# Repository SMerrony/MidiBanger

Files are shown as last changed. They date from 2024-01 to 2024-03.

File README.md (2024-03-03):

# MidiBanger
A Raspberry Pico* MIDI device that plays physical (toy) instruments via servos.

MidiBanger supports both percussive (mallet-type) and pressed (key-type) instruments.

* Pan-and-tilt mode using just two servos to play reachable notes
* Servo-per-note mode
* Solenoid-per-note mode (soon)

The current version supports up to 16 directly-connected servos, later versions may
support I2C servo controllers allowing hundreds of servos to be used. 

*Tested on Raspberry Pi Pico, Raspberry Pi Pico W, and Waveshare RP2040-Zero.

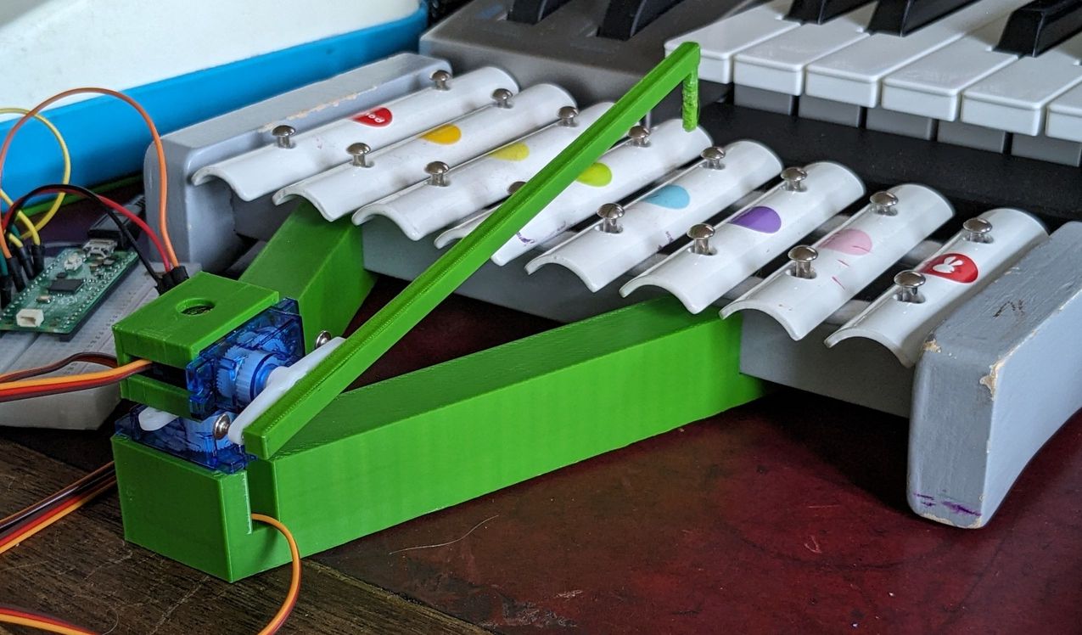
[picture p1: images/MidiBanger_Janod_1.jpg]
Pan-and-tilt version playing Janod toy glockenspiel


## Hardware Requirements
* Raspberry Pico or compatible such as RP2040-Zero
* Servo per note eg. SG90 9g Micro Servo, or a pair if using pan-and-tilt 
* Optional - Micro speaker - handy for debugging and setup
* Optional - 5V PSU for servos, if you think you need it
* Some 3D-printed parts to hold servos etc.

Some sample 3D parts are included in the `3D` directory, there are [FreeCAD](https://www.freecad.org/) designs and `.3mf` files
for slicing.

## Configuration
See the comments in `src/config.h` for details.

To avoid masses of commented-out congfiguration I have put the configuration that is specific to a
particular physical instrument in a separate file which is then `#include`d in the main `config.h`.
Example configurations are `chicco_toy_glock_config.h` and `janod_toy_glock_config.h`.

For the servo-per-note mode, the critical configuration item is the `NOTEPIN_INITIALISER`.  Leave its first line alone, then replace the contents with a maximum of sixteen [MIDI note number] = GPIO_PIN pairs.

For the two-servo pan-and-tilt mode it's the `NOTE_PAN_INITIALISER` that you will need to adjust to set the 
angles for each note.  This will be a trial-and-error process, I suggest you start by installing the servos so that
their centres of movement roughly point to the middle of the instrument and then do a first run WITHOUT the hammer attached.

If you are connecting up several MidiBangers I suggest you use a different string or
number for each one at the end of the `USB_PRODUCT` string.  It will make your life a lot simpler!

## Building
Don't forget to set `PICO_BOARD` to match your target microcontroller in `CMakeLists.txt`, then...
```
mkdir build
cd build
cmake ..
make
```
## Hints
### Pan-and-Tilt Players
* Try a metal-geared servo for the panning action, these seem to have less play than the plastic-geared equivalent.
* For greater accuracy playing large intervals (leaps) you can try setting the angles for the lowest and highest notes
just a little towards the centre, this will compensate for some overshoot.

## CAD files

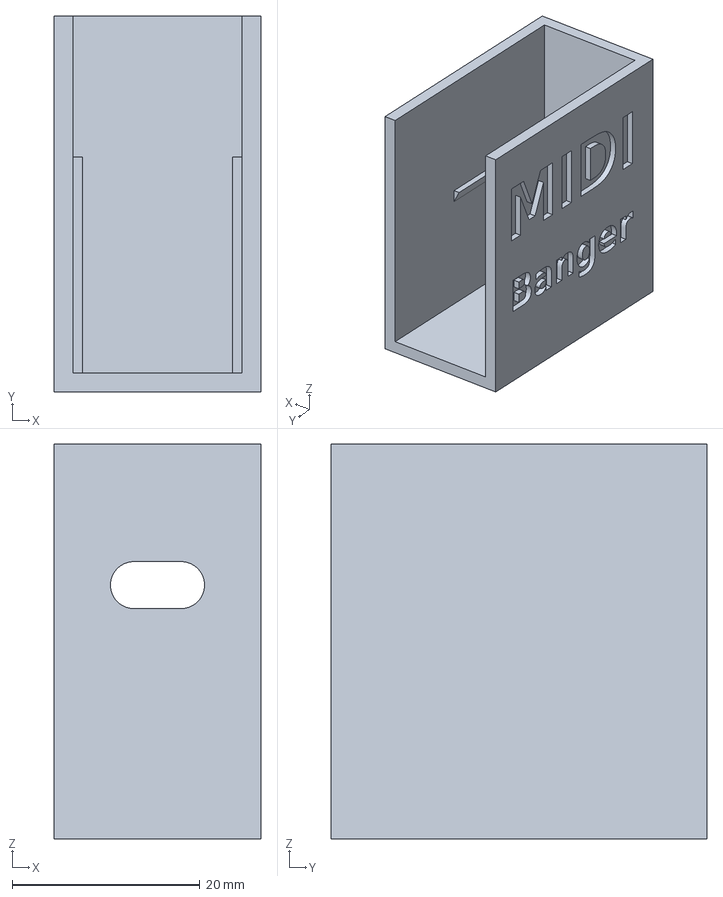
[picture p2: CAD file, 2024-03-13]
3D/RP2040_Zero_Case-Base_Body.3mf
22.0 x 40.0 x 42.0 mm

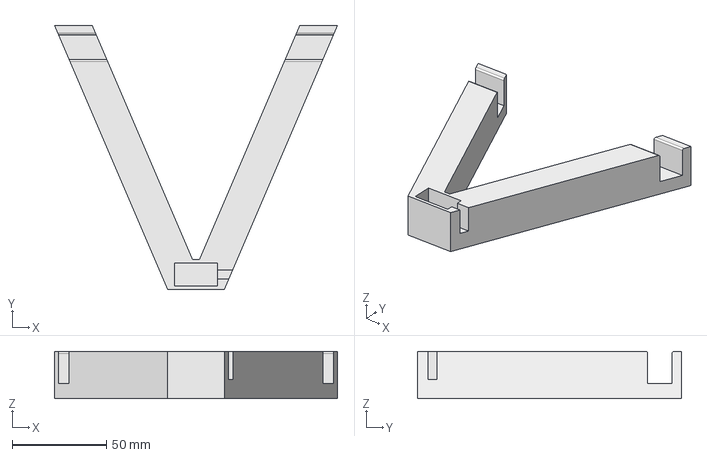
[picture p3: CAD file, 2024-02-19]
3D/ToyGlockPlayer/JanodBase.FCStd
150.0 x 140.0 x 25.0 mm

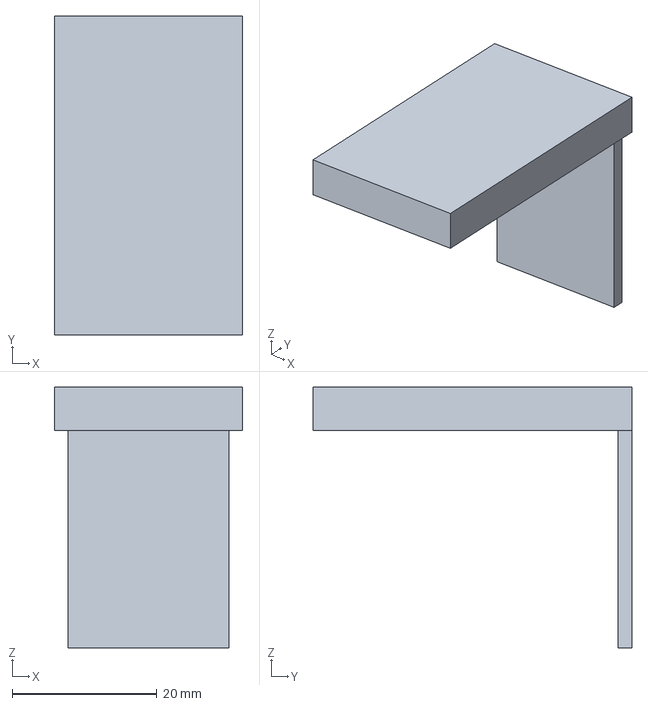
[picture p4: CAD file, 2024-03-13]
3D/RP2040_Zero_Case-Cover_Body.3mf
26.0 x 44.0 x 36.0 mm

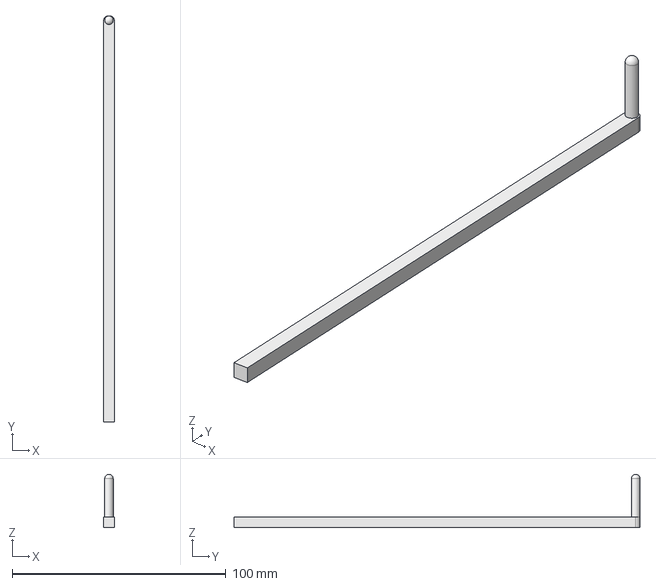
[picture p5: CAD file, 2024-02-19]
3D/ToyGlockPlayer/BeaterArm19cm.FCStd
5.00 x 190.0 x 25.0 mm

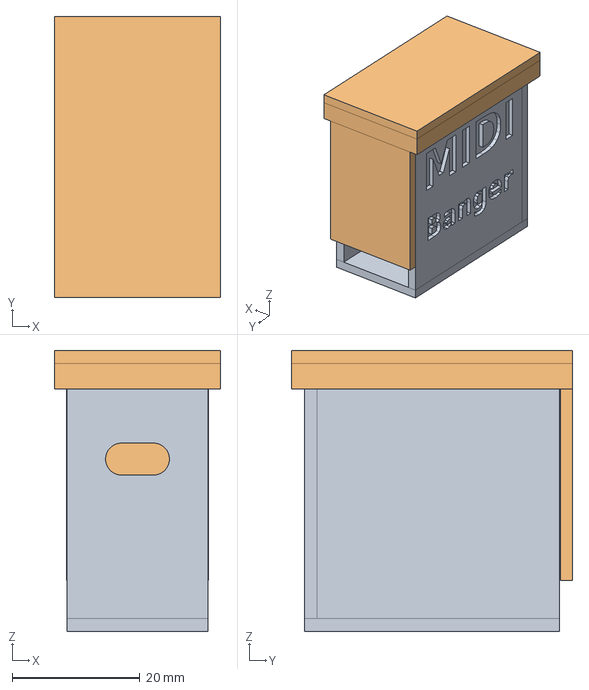
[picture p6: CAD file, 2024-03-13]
3D/RP2040_Zero_Case.FCStd
26.0 x 44.0 x 44.0 mm
Base_Body
Cover_Body

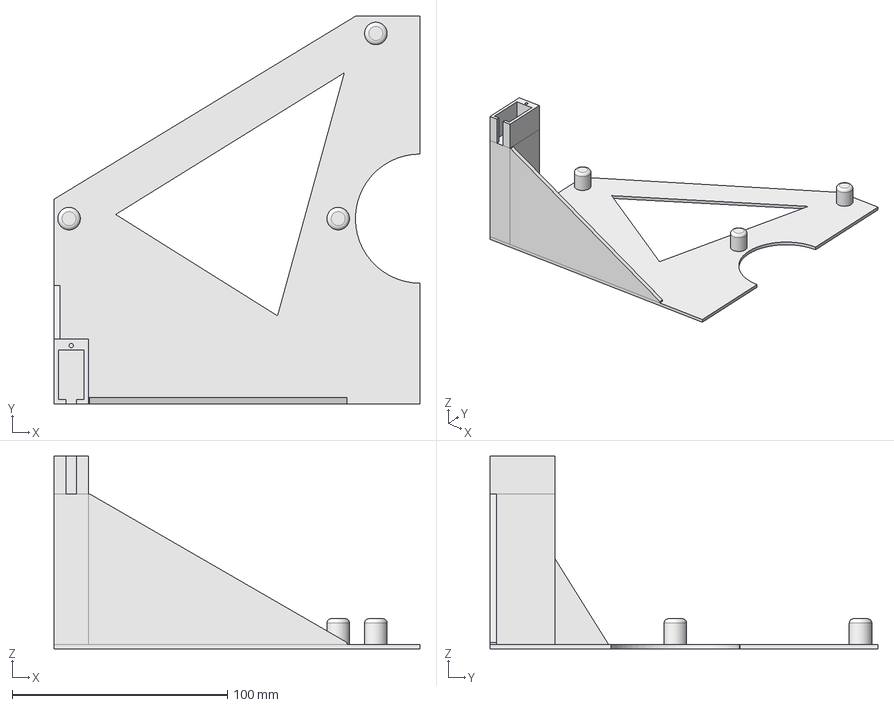
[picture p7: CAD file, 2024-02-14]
3D/ToyGlockPlayer/BasePlate.FCStd
170.0 x 180.0 x 89.5 mm

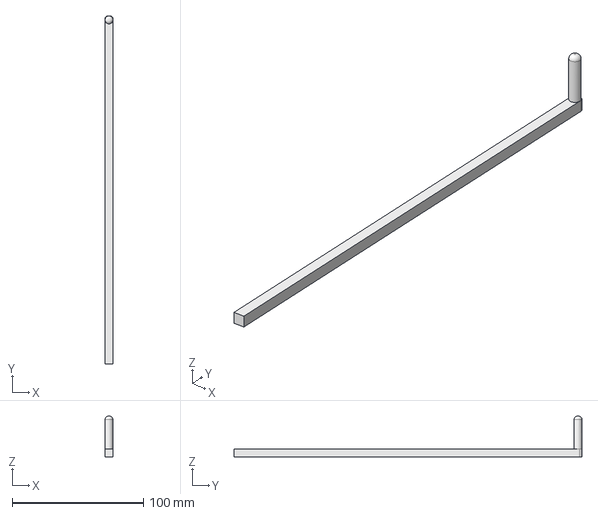
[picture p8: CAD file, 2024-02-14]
3D/ToyGlockPlayer/BeaterArm.FCStd
6.00 x 265.0 x 31.0 mm

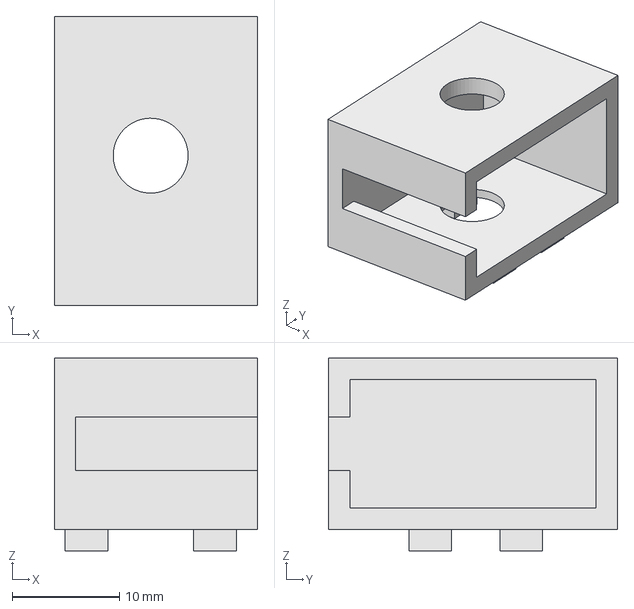
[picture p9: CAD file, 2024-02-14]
3D/ToyGlockPlayer/BeaterServoMount.FCStd
19.0 x 27.0 x 18.0 mm

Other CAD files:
3D/ToyGlockPlayer/BasePlate.3mf
3D/ToyGlockPlayer/BeaterArm.3mf
3D/ToyGlockPlayer/BeaterServoMount.3mf
3D/ToyGlockPlayer/JanodBase.3mf

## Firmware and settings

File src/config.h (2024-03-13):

/**
 * SPDX-FileCopyrightText: 2024 Stephen Merrony
 * SPDX-License-Identifier: BSD-3-Clause
 */

#pragma once

#define VERSION "0.1.0-dev"

#define USB_MANUFACTURER   "SMerrony"

// MIDI Channel to listen on. 
// N.B. This is expressed in the commonly-used MIDI channel numbering system 
// where the first channel is number 1 and the last is 16 (they are mapped internally to 0 ... 15).
#define MIDI_CHANNEL 1

// Speaker is just for debugging, set to false otherwise (it uses 1 of the 16 PWM channels)
#define WITH_SPEAKER false
#define SPEAKER_PIN 15 

// General servo characteristics, these are the spec. values, you may be able to exceed them.
#define SERVO_HZ 50
#define SERVO_MIN_DUTY 500
#define SERVO_MAX_DUTY 2400
#define SERVO_MIN_ANGLE 0
#define SERVO_MAX_ANGLE 180

// do not edit...
#define NOTE_NOT_MAPPED 0
// The MIDI notes, C4 is middle-C in MIDI-speak.
typedef int notepins_t[128];
typedef uint16_t noteangle_t[128];
// Internal indices for the P&T servos - i.e which of the servos[] array to use
#define PAN_SERVO 0
#define TILT_SERVO 1  
// ...end of do not edit section

/*
// The mapping of MIDI note numbers to GPIO pins for controlling the servos...
#define NOTE_PIN_INITIALISER { [0 ... 127] = NOTE_NOT_MAPPED,\
                                [72] = 2,\
                                [74] = 3,\
                                [76] = 4,\
                                [77] = 5,\
                                [79] = 6,\
                                [81] = 7,\
                                [83] = 8,\
                                [84] = 9 };
*/                                

// Here you must #include a config file specific to the instrument you are playing
#include "chicco_toy_glock_config.h"
// #include "janod_toy_glock_config.h"

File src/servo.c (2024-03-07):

/**
 * SPDX-FileCopyrightText: 2023 Stephen Merrony
 * SPDX-License-Identifier: BSD-3-Clause
 */

#include "servo.h"

#include "hardware/clocks.h"
#include "hardware/pwm.h"

#include "config.h"

static servo_t servos[MAX_SERVOS] = {0};

static int servos_in_use = 0;

/* resetter_task performs the percussive returns.
   It loops over each servo and checks if its reset time has passed.
   N.B. Must not be called until all servo_setup() calls are completed. */
void resetter_task() {
	while (true){
		for (int s = 0; s < servos_in_use; ++s) {
			if (! is_at_the_end_of_time(servos[s].reset)) {
				if (absolute_time_diff_us(servos[s].reset, get_absolute_time()) > 0) {
					servo_set_angle(s, servos[s].min_angle);
					servos[s].reset = at_the_end_of_time;
				}
			}
		}
		busy_wait_ms(2);
	}
}

/* setup_servo initialises a servo_t struct according to the passed parameters and then start the PWM
               by calling servo_start.  It must be called before using the servo. 
               The duty parameters are expressed in microseconds, the angles in degrees.
    @param servo index
    @param pin   GPIO pin number
    @param zero_duty 
    @param full_duty
    @param min_angle in degrees for this 'mallet'
    @param max_angle in degrees */
void servo_setup(int servo, uint pin, uint16_t zero_duty, uint16_t full_duty, uint16_t min_angle, uint16_t max_angle) {
    servos[servo].pin = pin;
    servos[servo].zero_duty = zero_duty;
    servos[servo].full_duty = full_duty;
    servos[servo].min_angle = min_angle;
    servos[servo].max_angle = max_angle;

    // precalculate the ranges for efficiency when setting the angle
    servos[servo].duty_range = full_duty - zero_duty;
    servos[servo].angle_range = max_angle - min_angle;

    gpio_set_function(servos[servo].pin, GPIO_FUNC_PWM);
    servos[servo].slice_num = pwm_gpio_to_slice_num(servos[servo].pin);

    servos[servo].configured = true;

    uint32_t clock  = clock_get_hz(clk_sys);
    uint32_t divisor = clock / SERVO_HZ;

    pwm_config config = pwm_get_default_config();
    pwm_config_set_clkdiv(&config, (float)divisor);
    pwm_config_set_wrap(&config, 20000);
    pwm_init(servos[servo].slice_num, &config, false);

    servos[servo].reset = at_the_end_of_time;

    if (MULTI_PERCUSSION) {
        servo_start(servo, min_angle);
    }

    // servo_set_angle(servo, 90);
    // busy_wait_ms(PERCUSSIVE_RETURN_MS);
    // servo_set_angle(servo, 0);

    servos_in_use++;
}

/* servo_start initialises a servo
    @param s servo index into servos[] array
    @param start_angle initial angle in degrees */
void servo_start(const int s, uint16_t start_angle) {
    const uint chan = pwm_gpio_to_channel(servos[s].pin);
    uint16_t pulse = (start_angle - servos[s].min_angle) * servos[s].full_duty / servos[s].angle_range + servos[s].zero_duty;
    pwm_set_chan_level(servos[s].slice_num, chan, pulse);
    pwm_set_enabled(servos[s].slice_num, true);
}

void servo_stop(const int servo) {
    if ((servo < MAX_SERVOS) && servos[servo].configured) {
        pwm_set_enabled(servos[servo].slice_num, false);
    }
}

/* servo_set_angle moves a servo
    @param s servo index into servos[] array
    @param angle in degrees */
void servo_set_angle(const int s, uint16_t angle) {
    if ((s < MAX_SERVOS) && servos[s].configured) {
        const uint chan = pwm_gpio_to_channel(servos[s].pin);
        const uint16_t level = (angle - servos[s].min_angle) * servos[s].full_duty / servos[s].angle_range + servos[s].zero_duty;
        pwm_set_chan_level(servos[s].slice_num, chan, level);
    }
}

void servo_set_reset_time(int servo, absolute_time_t when) {
    servos[servo].reset = when;
}

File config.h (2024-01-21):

/**
 * SPDX-FileCopyrightText: 2024 Stephen Merrony
 * SPDX-License-Identifier: BSD-3-Clause
 */

#ifndef CONFIG_H
#define CONFIG_H

// Servo characteristics
#define SERVO_MIN_DUTY 500
#define SERVO_MAX_DUTY 2400
#define SERVO_MIN_ANGLE 0
#define SERVO_MAX_ANGLE 180

#define PERCUSSION true		    // is this is a mallet-type instrument where the 'hammer' is returned after striking?
#define PERCUSSIVE_RETURN_MS 75 // period before 'hammer' starts to return (may influence length of stroke)

#define NOTE_NOT_MAPPED -1

// The MIDI notes, C4 is middle-C in MIDI-speak.
typedef int notepins_t[128];

#define NOTEPIN_INITIALISER { [0 ... 127] = NOTE_NOT_MAPPED,\
                                [72] = 2,\
                                [74] = 3,\
                                [76] = 4,\
                                [77] = 5,\
                                [79] = 6,\
                                [81] = 7,\
                                [83] = 8,\
                                [84] = 9 };



#endif

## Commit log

2023-07-27 Basic servo action!
2023-07-28 Improve servo code and make more general.
2023-07-29 Implement servo_map and servo_for_note()
2023-07-30 Fix note-to-solenoid mapping
2024-01-21 Comment out GPIO stuff, fix note mapping.
    [config.h, midi.c, servo.c]
2024-01-22 Add README, channel filter, comments...
2024-02-14 Add pan-and-tilt mode.
    [Calcs.ods]
2024-02-14 Add 3D files, fix fast repeat for same note.
    [BasePlate.3mf, BasePlate.FCStd, BeaterArm.3mf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]
2024-02-19 Add photo and more 3D files.
    [BeaterArm19cm.FCStd, Calcs.ods, JanodBase.3mf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]
2024-02-25 Tweaks for new pan solenoid on Janod
    [Calcs.ods]
2024-03-03 Multiple small changes and doc/comment improvements
    [Calcs.ods]
2024-03-04 Fix octaves for toy glock configs.
    [chicco_toy_glock_config.h, janod_toy_glock_config.h]
2024-03-07 Fix and parameterise PWM freq for servos.
    [Calcs.ods]
2024-03-13 Add 3D models, config tweaks
    [RP2040_Zero_Case-Base_Body.3mf, RP2040_Zero_Case-Cover_Body.3mf, RP2040_Zero_Case.FCStd]
